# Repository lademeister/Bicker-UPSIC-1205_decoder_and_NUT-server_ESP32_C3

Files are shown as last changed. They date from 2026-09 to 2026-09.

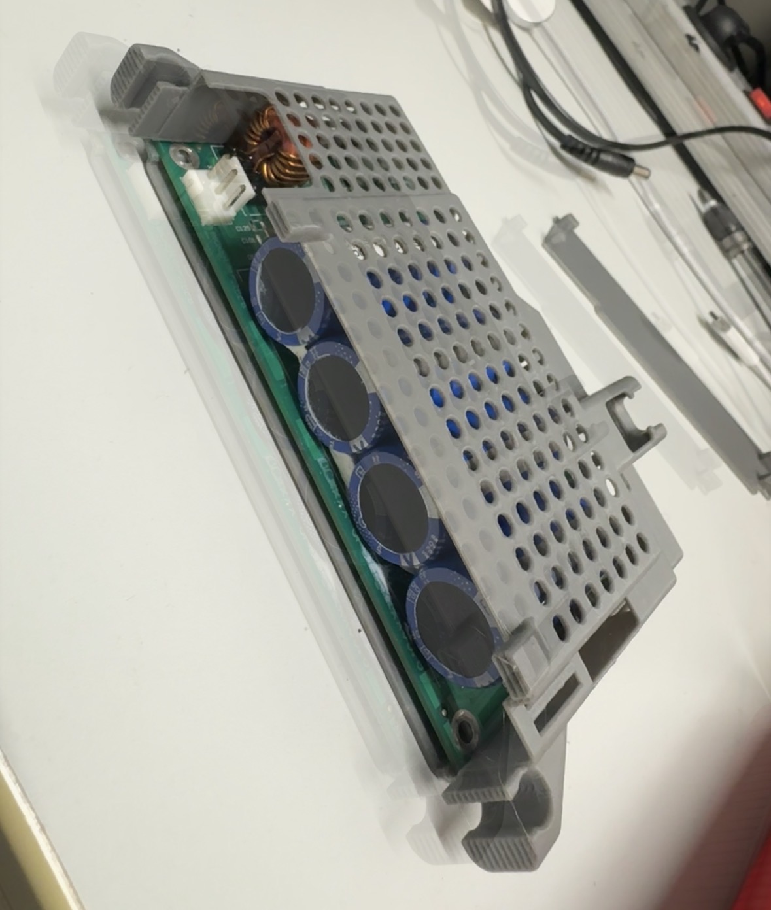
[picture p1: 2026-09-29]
Images Bicker UPSIC-1205 usage/3D printed case2.jpg

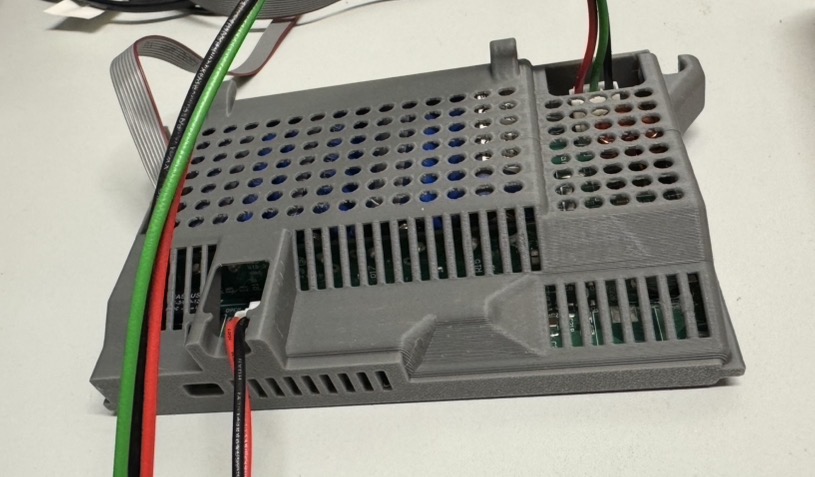
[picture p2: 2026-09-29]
Images Bicker UPSIC-1205 usage/3D printed case4.jpg

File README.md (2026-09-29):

# Bicker-UPSIC-1205 Decoder and NUT Server for ESP32-C3

This code does **NOT** require the optional and expensive **PSZ-1063 module**, as it reads the registers from the UPS module directly via I²C.

It provides:

- **NUT Server (Network UPS Tools) via Wi-Fi**
  - You can use the NUT data on multiple computers in the network.
  - It can be used for monitoring, server shutdown, etc.

- **MQTT publishing** of internal device data

- **Home Assistant Auto Discovery**
  - The UPS appears as an MQTT device in Home Assistant.

- **Optional 128×32 OLED display**
  - Shows the current UPS status.
  - Shows a remaining-runtime countdown while running on battery/supercapacitor power.

- **Optional programmable LED strip**
  - Can display the charge percentage like a bar graph.
  - Green when full.
  - Fewer LEDs as the charge level decreases.
  - Red when almost empty.
  - Flashing red shortly before power-off.
  - The behavior can be customized.

---

## Example MQTT Data

Typical data while running from mains power may look like this:

```text
UPS Charge  100 %
UPS Current 28 mA
UPS Power   0 W
UPS Runtime 0.00 s
UPS Voltage 12 V
```

The `runtime` value is used to **live-calculate the estimated remaining runtime** when running from the supercapacitors, for example after a power loss.

For this, a live calculation is performed based on the output power consumption.

The calculation uses the internal voltage and current draw, measured before the voltage converter that generates the stable 12 V output.

From this, we derive the actual wattage of the output load and calculate it back against the available energy stored in the supercapacitors.

From that, we can estimate the remaining runtime in seconds.

---

## Current Reading

The `Current` value is the actual charge/discharge current of the supercapacitors.

It will therefore be negative during a power loss and typically around approximately ±30 mA when normally powered.

Note that this is the actual current on the supercapacitor side.

As the supercapacitor voltage drops, the current must increase in order to maintain constant power at the regulated 12 V UPS output.

Therefore, you may easily see currents of around 6 A or more while your connected 12 V device only draws around 1.5 A.

This is because:

```text
P = U × I
```

Power = Voltage × Current

Therefore:

```text
P(supercapacitors) ≈ P(output)
```

The lower the supercapacitor voltage becomes, the higher the current must be to maintain approximately the same output power after boosting the voltage to 12 V.

---

## Reverse Engineering

I did the reverse engineering using a trial-and-error approach, without any knowledge of the internal register layout.

Therefore, some of my assumptions may be wrong.

However, the data derived from the module using this code appears to be quite plausible and consistent.

We decode internal register data and status information such as:

- Charge percentage
- Current
- Voltage
- Runtime
- Power status
- Other UPS status information

This code is written for the **ESP32-C3** and does **NOT** require the optional PSZ-1063 add-on module.

No serial converter or level converter is needed for the connection described here.

The ESP32 communicates directly with the small 14-pin header on the side of the UPSIC-1205.

---

## I²C Connection

For I²C communication, we only need:

```text
Pin 11  GND
Pin 12  SDA
Pin 14  SCL
```

Be very sure to count the pins correctly.

**Pin 13 is directly next to the communication pins and carries 12 V.**

Connecting Pin 13 accidentally to an ESP32 GPIO would most likely damage the ESP32.

Pin 13 could theoretically be used as a power source for the ESP32, but its maximum current of approximately 300 mA is somewhat low considering possible current spikes during Wi-Fi transmission.

You may therefore want to add a sufficiently large capacitor or simply power the ESP32 separately.

Make sure to also connect **GND between the ESP32 and the Bicker UPSIC-1205 using Pin 11**, as this provides the common voltage reference required for the I²C clock and data lines, SCL and SDA.

---

## Full Pinout

For completeness, here is the full connector pinout.

You do **NOT** need the DSUB9 connector.

You do **NOT** need the extension module.

The information normally available through those interfaces can also be accessed with this code directly from the internal registers and made available over the network via the standard NUT integration.

| Pin | Signal | DSUB9 |
|---:|---|---:|
| 01 | DCD at PC – cable connected detection | 1 |
| 02 | DSR at PC – capacitor charge-state detection | 6 |
| 03 | TXD – connected to RX at PC | 2 |
| 04 | RTS at PC – supply voltage | 7 |
| 05 | RXD – connected to TX at PC | 3 |
| 06 | CTS at PC – power-fail detection | 8 |
| 07 | N/A | |
| 08 | N/A | 9 |
| 09 | GND | 5 |
| 10 | SMBAlert | |
| **11** | **🟢 GND** | |
| **12** | **🟢 xSDA / I²C** | |
| 13 | Vout 12 V, max. 300 mA | |
| **14** | **🟢 xSCL / I²C** | |

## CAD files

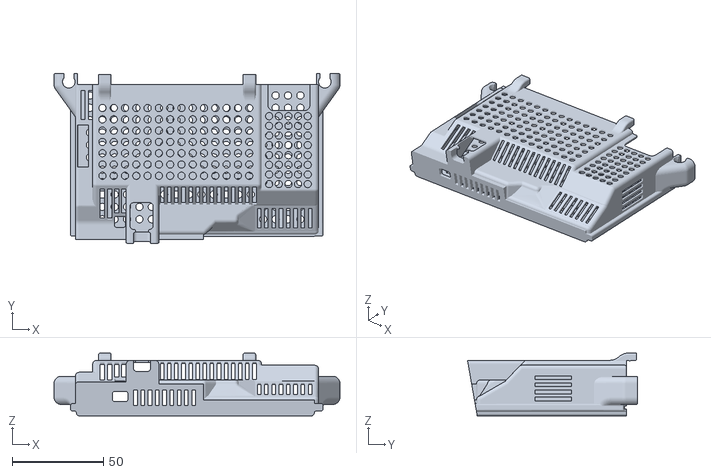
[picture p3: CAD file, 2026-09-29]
Bicker UPSIC-1205 Case 3D Print/BICKER UPSIC-1205_GEHAEUSE.stl
157.1 x 93.4 x 34.6

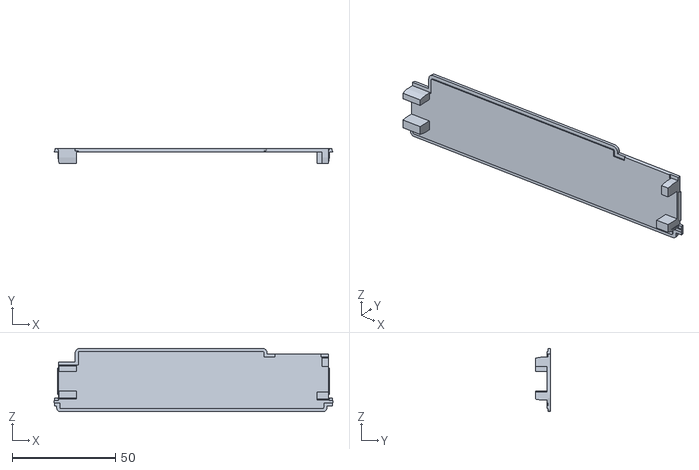
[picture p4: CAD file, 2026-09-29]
Bicker UPSIC-1205 Case 3D Print/BICKER UPSIC-1205_Gehaeusedeckel.stl
135.0 x 7.40 x 30.6

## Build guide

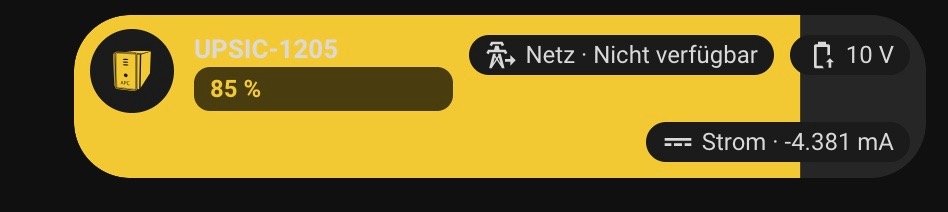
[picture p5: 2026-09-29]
Images Bicker UPSIC-1205 usage/Home Assitant Integration3.jpeg

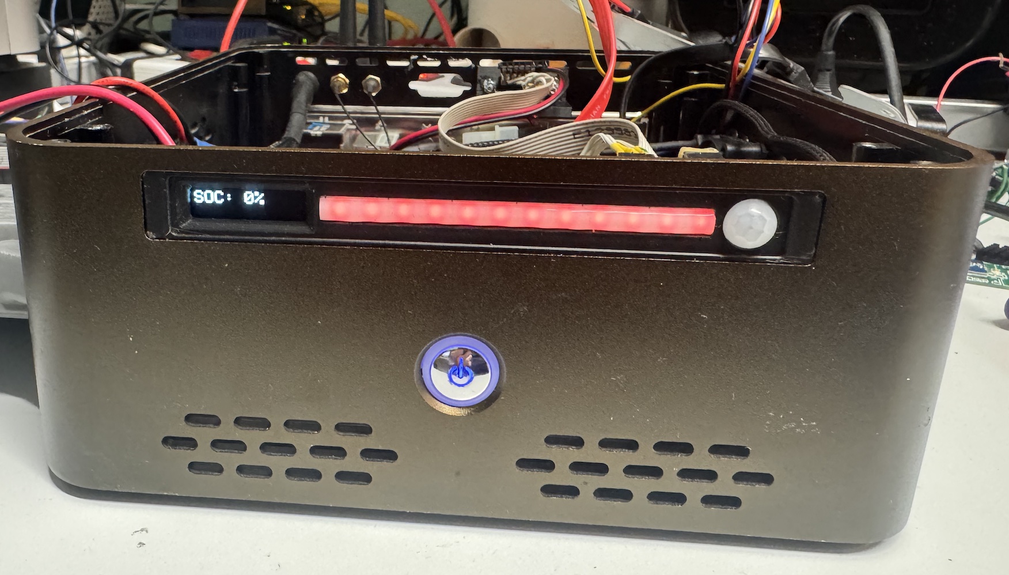
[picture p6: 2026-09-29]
Images Bicker UPSIC-1205 usage/OLED_and_LED_Bargraph_SOC0.jpg

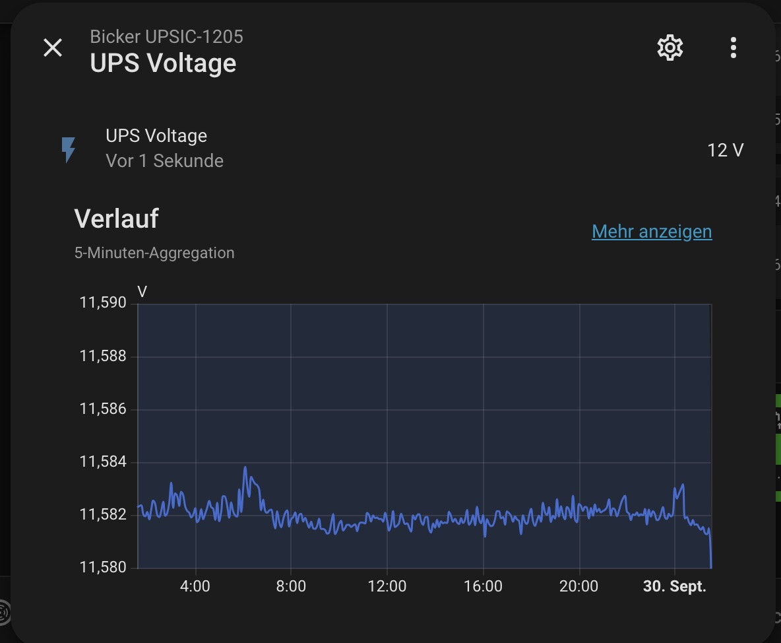
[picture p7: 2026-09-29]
Images Bicker UPSIC-1205 usage/Home Assitant Integration2.jpg

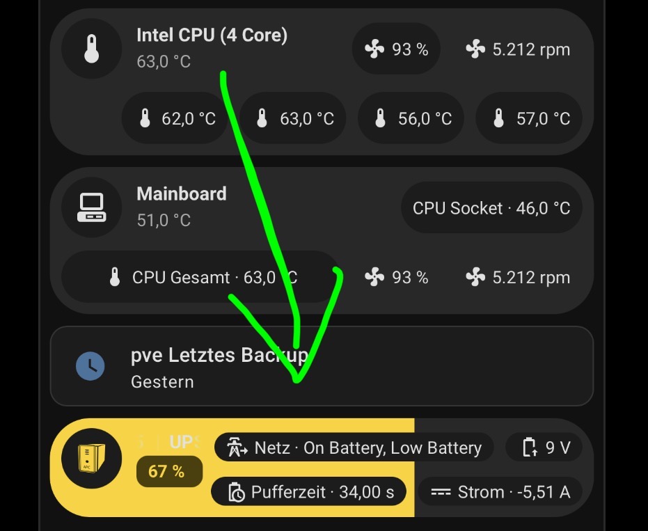
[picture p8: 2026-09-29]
Images Bicker UPSIC-1205 usage/Home Assitant Integration4.jpg

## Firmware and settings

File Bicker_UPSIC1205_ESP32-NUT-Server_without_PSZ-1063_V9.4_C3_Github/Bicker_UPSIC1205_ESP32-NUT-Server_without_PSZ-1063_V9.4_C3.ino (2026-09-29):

#include <Arduino.h>

#include "config.h"
#include "powercap.h"
#include "nutserver.h"
#include "runtime.h"
#include "ota.h"
#include "wifi_setup.h"
#include "ha_discovery.h"
#include <Wire.h>
//#include "SSD1306Ascii.h"
//#include "SSD1306AsciiWire.h"
#include <Adafruit_NeoPixel.h>
#include <Adafruit_GFX.h>
#include <Adafruit_SSD1306.h>
#include <PubSubClient.h>


HADiscovery haDiscovery;

WiFiClient mqttWiFiClient;
PubSubClient mqttClient(mqttWiFiClient);
unsigned long lastMQTTReconnect = 0;


uint8_t ledBrightness = 25;
Adafruit_NeoPixel ledstrip(NUM_LEDS, LED_PIN, NEO_GRB + NEO_KHZ800);
Adafruit_NeoPixel RGB_LED_onboard(1, 8, NEO_GRB + NEO_KHZ800);

//SSD1306AsciiWire oled;


static bool lastOnBattery = false;
static bool powerLossFlash = false;
static uint8_t flashCount = 0;
static bool flashState = false;
static unsigned long lastFlash = 0;


PowerCap powercap;

NUTServer nut;

RuntimeEstimator runtime;

OTAUpdater ota;

WiFiManagerESP wifi;

unsigned long lastPowerUpdate = 0;
unsigned long lastOLEDUpdate = 0;
unsigned long lastLEDUpdate = 0;
uint32_t lastMotionTime = 0;
bool oledOn = false;

PowerCapData displayData;

Adafruit_SSD1306 display(
  SCREEN_WIDTH,
  SCREEN_HEIGHT,
  &Wire,
  OLED_RESET
);

#include <Fonts/FreeSans9pt7b.h>
/*
FreeSans9pt7b
FreeSans12pt7b
FreeSansBold12pt7b
FreeMono9pt7b
FreeMonoBold12pt7b
 */


unsigned long lastUpdate = 0;

//void init_oled(){
//  //Wire.begin();         
//  oled.begin(&Adafruit128x32, I2C_ADDRESS_OLED);
//  oled.set400kHz();  
//  oled.setFont(Adafruit5x7); 
//  oled.set2X(); 
//
//  uint32_t m = micros();
//  oled.clear();  
//  oled.println("Bicker");
//  oled.println("UPSIC-1205");
//  delay(1000);
//  oled.clear();  
//}


void init_oled(){
  if(!display.begin(SSD1306_SWITCHCAPVCC,I2C_ADDRESS_OLED))
  {
    Serial.println("##### OLED failed #####");
    //while(true);
  }
  else{
    display.ssd1306_command(SSD1306_SEGREMAP | 0x0);
    display.ssd1306_command(SSD1306_COMSCANINC);


    display.clearDisplay();
    display.display();
    display.setTextSize(2);
    display.setTextColor(SSD1306_WHITE);
    display.setCursor(0,0);
    display.println("Bicker");
    display.println("UPSIC-1205");
    display.display();
    delay(2500);
    display.clearDisplay();
    display.display();
  }
}

void init_neopixel(){
  ledstrip.begin();
  RGB_LED_onboard.begin();
  ledstrip.setBrightness(LEDstrip_global_brightness_setting);
  RGB_LED_onboard.setBrightness(50);
//  RGB_LED_onboard.setPixelColor(0, 0, 0, 255);
//  delay(100);
//  RGB_LED_onboard.setPixelColor(0, 0, 255, 0);
//  delay(100);
  RGB_LED_onboard.setPixelColor(0, 0, 0, 0);
  //for (int i = 0; i < NUM_LEDS; i++) ledstrip.setPixelColor(i, rot, gruen, blau);
  for (int i = 0; i < NUM_LEDS; i++) ledstrip.setPixelColor(i, 0, 25, 0);
  delay(100);
  ledstrip.show();
  for (int i = 0; i < NUM_LEDS; i++) ledstrip.setPixelColor(i, 0, 0, 0);
  //ledstrip.setPixelColor(2, 5, 0, 0);
  ledstrip.show();
}

uint32_t fadeColor(
  uint32_t oldColor,
  uint32_t newColor,
  float amount
)
{

  uint8_t r1 =
    (oldColor >> 16) & 0xFF;

  uint8_t g1 =
    (oldColor >> 8) & 0xFF;

  uint8_t b1 =
    oldColor & 0xFF;


  uint8_t r2 =
    (newColor >> 16) & 0xFF;

  uint8_t g2 =
    (newColor >> 8) & 0xFF;

  uint8_t b2 =
    newColor & 0xFF;



  uint8_t r =
    r1 + (r2-r1)*amount;

  uint8_t g =
    g1 + (g2-g1)*amount;

  uint8_t b =
    b1 + (b2-b1)*amount;


  return ledstrip.Color(r,g,b);

}

//void updateLEDs()
//{
//
//  static uint32_t currentColors[NUM_LEDS];
//
//  static bool blinkState = false;
//
//  static unsigned long lastBlink = 0;
//
//
//  if(
//    millis()-lastBlink > 500
//  )
//  {
//
//    lastBlink = millis();
//
//    blinkState = !blinkState;
//
//  }
//
//
//
//  float soc =
//    constrain(
//      displayData.soc,
//      0,
//      100
//    );
//
//
//  uint8_t activeLEDs =
//    map(
//      soc,
//      0,
//      100,
//      0,
//      NUM_LEDS
//    );
//
//
//
//  bool critical =
//    (
//      displayData.onBattery &&
//      soc < 90
//    );
//
//
//
//  bool charging =
//    displayData.charging;
//
//
//
//  for(
//    int i=0;
//    i<NUM_LEDS;
//    i++
//  )
//  {
//    int pixel = NUM_LEDS - 1 - i;
//
//    uint32_t target;
//
//
//
//    // -------------------------
//    // Charging animation
//    // -------------------------
//
//    if(charging)
//    {
//
//      uint8_t wave =
//        //(millis()/50+i*20)%255;
//        (millis()/50+(NUM_LEDS-1-i)*20)%255; //inverted direction
//
//
//      target =
//        ledstrip.Color(
//          wave,
//          0,
//          80
//        );
//
//    }
//
//
//
//
//
//
//
//    // -------------------------
//    // SOC bargraph
//    // -------------------------
//
//    else if(i < activeLEDs)
//    {
//
//      if(soc > 60)
//      {
//
//        target =
//          ledstrip.Color(
//            0,
//            ledBrightness,
//            0
//          );
//
//      }
//
//      else if(soc > 30)
//      {
//
//        target =
//          ledstrip.Color(
//            ledBrightness,
//            ledBrightness,
//            0
//          );
//
//      }
//
//      else
//      {
//
//        target =
//          ledstrip.Color(
//            ledBrightness,
//            0,
//            0
//          );
//
//      }
//
//    }
//
//
//    // -------------------------
//    // empty LEDs
//    // -------------------------
//
//    else
//    {
//
//      target =
//        ledstrip.Color(8,0,0);
//    }
//
//
//
//    // -------------------------
//    // first LED warning blink
//    // -------------------------
//
//    if(
//      critical &&
//      i==0
//    )
//    {
//
//      if(blinkState)
//      {
//        target =
//          ledstrip.Color(
//            0,
//            ledBrightness,
//            0
//          );
//      }
//      else
//      {
//        target =
//          ledstrip.Color(
//            ledBrightness,
//            0,
//            0
//          );
//      }
//
//    }
//
//
//
//    uint32_t old =
//      currentColors[i];
//
//
//    currentColors[i] =
//      fadeColor(
//        old,
//        target,
//        0.15
//      );
//
//
//    //ledstrip.setPixelColor(i,currentColors[i]);
//    ledstrip.setPixelColor(pixel,currentColors[i]);
//
//
//  }
//
//
//  ledstrip.show();
//
//}


//void updateLEDs()
//{
//  static uint32_t currentColors[NUM_LEDS];
//  static bool blinkState = false;
//  static bool fastBlinkState = false;
//  static unsigned long lastBlink = 0;
//  static unsigned long lastFastBlink = 0;
//
//  if(millis()-lastBlink > 500)
//  {
//    lastBlink = millis();
//    blinkState = !blinkState;
//  }
//
//  if(millis()-lastFastBlink > 150)
//  {
//    lastFastBlink = millis();
//    fastBlinkState = !fastBlinkState;
//  }
//
//
//  float soc = constrain(displayData.soc,0,100);
//
//  uint8_t activeLEDs = map(soc,0,100,0,NUM_LEDS);
//
//  bool critical = displayData.onBattery && soc < 90;
//  bool veryLow = displayData.onBattery && soc < 30;
//  bool charging = displayData.charging;
//
//
//  uint32_t barColor;
//
//  if(soc > 60)
//    barColor = ledstrip.Color(0,ledBrightness,0);
//  else if(soc > 30)
//    barColor = ledstrip.Color(ledBrightness,ledBrightness,0);
//  else
//    barColor = ledstrip.Color(ledBrightness,0,0);
//
//
//
//  for(int i=0;i<NUM_LEDS;i++)
//  {
//    int pixel = NUM_LEDS-1-i;
//
//    uint32_t target;
//
//
//    // SOC bargraph
//    if(i < activeLEDs)
//    {
//      target = barColor;
//    }
//
//    // inactive LEDs
//    else
//    {
//      if(charging)
//        target = ledstrip.Color(8,0,8);   // dark purple
//      else
//        target = ledstrip.Color(8,0,0);   // dark red
//    }
//
//
//
//    // low battery warning
//    if(critical && i==0)
//    {
//
//      if(veryLow)
//      {
//        // fast red flash below 30%
//        if(fastBlinkState)
//          target = ledstrip.Color(ledBrightness,0,0);
//        else
//          target = ledstrip.Color(0,0,0);
//      }
//      else
//      {
//        // normal warning blink
//        if(blinkState)
//          target = barColor;
//        else
//          target = ledstrip.Color(ledBrightness,0,0);
//      }
//
//    }
//
//
//
//    currentColors[i] =
//      fadeColor(
//        currentColors[i],
//        target,
//        0.15
//      );
//
//
//    ledstrip.setPixelColor(
//      pixel,
//      currentColors[i]
//    );
//
//  }
//
//
//  ledstrip.show();
//}



void updateLEDs()
{
//  static uint32_t currentColors[NUM_LEDS];
//  static bool blinkState = false;
//  static bool fastBlinkState = false;
//  static unsigned long lastBlink = 0;
//  static unsigned long lastFastBlink = 0;

  static uint32_t currentColors[NUM_LEDS];
  static bool blinkState = false;
  static bool fastBlinkState = false;
  static unsigned long lastBlink = 0;
  static unsigned long lastFastBlink = 0;

  static bool lastOnBattery = false;
  static bool powerLossFlash = false;
  static uint8_t flashCount = 0;
  static bool flashState = false;
  static unsigned long lastFlash = 0;

  uint32_t now = millis();
  // detect transition from grid power to battery
if(displayData.onBattery && !lastOnBattery)
{
  powerLossFlash = true;
  flashCount = 0;
  flashState = true;
  lastFlash = now;
}

lastOnBattery = displayData.onBattery;


// 4x full red flash on power loss
  if(powerLossFlash)
  {
    if(now - lastFlash > 200)
    {
      lastFlash = now;
      flashState = !flashState;
  
      if(!flashState)
      {
        flashCount++;
  
        if(flashCount >= 4)
          powerLossFlash = false;
      }
    }
  
  
    uint32_t flashColor;
  
    if(flashState){
      //flashColor = ledstrip.Color(ledBrightness,0,0);
      ledstrip.setBrightness(flashBrightness);
      flashColor = ledstrip.Color(flashBrightness,0,0);
    }
    else{
      flashColor = ledstrip.Color(0,0,0);
    }
  
    for(int i=0;i<NUM_LEDS;i++)
    {
      ledstrip.setPixelColor(i, flashColor);
    }
  
    ledstrip.show();
    return;
  }

  else{
    ledstrip.setBrightness(LEDstrip_global_brightness_setting);
  }

  
  if(millis()-lastBlink > 500)
  {
    lastBlink = millis();
    blinkState = !blinkState;
  }

  if(millis()-lastFastBlink > 150)
  {
    lastFastBlink = millis();
    fastBlinkState = !fastBlinkState;
  }


  float soc = constrain(displayData.soc,0,100);

  uint8_t activeLEDs = map(soc,0,100,0,NUM_LEDS);

  bool critical = displayData.onBattery && soc < 90;
  bool veryLow = displayData.onBattery && soc < 30;
  bool charging = displayData.charging;


  uint32_t barColor;

//  if(soc > 60)
//    barColor = ledstrip.Color(0,ledBrightness,0);
//  else if(soc > 30)
//    barColor = ledstrip.Color(ledBrightness,ledBrightness,0);
//  else
//    barColor = ledstrip.Color(ledBrightness,0,0);


    if(displayData.onBattery && soc < 30)
    {
      // critical battery
      barColor = ledstrip.Color(ledBrightness,0,0);
    }
    else if(displayData.onBattery && soc < 95)
    {
      // battery discharge warning (orange/red)
      barColor = ledstrip.Color(ledBrightness,60,0);
    }
    else
    {
      if(soc > 60)
        barColor = ledstrip.Color(0,ledBrightness,0);
      else if(soc > 30)
        barColor = ledstrip.Color(ledBrightness,ledBrightness,0);
      else
        barColor = ledstrip.Color(ledBrightness,0,0);
    }

  for(int i=0;i<NUM_LEDS;i++)
  {
    int pixel = NUM_LEDS-1-i;

    uint32_t target;


    // SOC bargraph
    if(i < activeLEDs)
    {
      target = barColor;
    }

    // inactive LEDs
    else
    {
      if(charging)
        target = ledstrip.Color(8,0,8);   // dark purple
      else
        target = ledstrip.Color(8,0,0);   // dark red
    }



//    // low battery warning
//    if(critical && i==0)
//    {
//
//      if(veryLow)
//      {
//        // fast red flash below 30%
//        if(fastBlinkState)
//          target = ledstrip.Color(ledBrightness,0,0);
//        else
//          target = ledstrip.Color(0,0,0);
//      }
//      else
//      {
//        // normal warning blink
//        if(blinkState)
//          target = barColor;
//        else
//          target = ledstrip.Color(ledBrightness,0,0);
//      }
//
//    }



    currentColors[i] =
      fadeColor(
        currentColors[i],
        target,
        0.15
      );


    ledstrip.setPixelColor(
      pixel,
      currentColors[i]
    );

  }


  ledstrip.show();
}

void setup()
{

  Serial.begin(115200);

  delay(500);



  Serial.println();
  Serial.println("===============================");
  Serial.println(" Bicker UPSIC-1205 NUT ESP32");
  Serial.println("===============================");

  pinMode(PIR_pin, INPUT_PULLDOWN);


  // -------------------------
  // I2C PowerCap
  // -------------------------

  powercap.begin(); //incl i2c init
  Serial.println("PowerCap initialized");


  init_oled();
  init_neopixel();

  runtime.begin();

  // -------------------------
  // WiFi
  // -------------------------

  wifi.begin();


  Serial.print("IP: ");
  Serial.println(
    wifi.getIP()
  );



  // -------------------------
  // OTA
  // -------------------------

  ota.begin();



  // -------------------------
  // NUT Server
  // -------------------------

  nut.begin();


  Serial.println(
    "NUT server started on port 3493"
  );

  mqttClient.setServer(
  MQTT_SERVER,
  MQTT_PORT
);
mqttClient.setBufferSize(1024);

haDiscovery.begin(mqttClient);

}


//void oled_update(){
//  oled.clear();  
//  oled.println("USV");
//  oled.print("SOC = ");
//  oled.print(data.soc,1);
//  oled.println(" %");
//}

void updateOLED()
{
//  if(displayData.soc>99){
//    display.clearDisplay();
//    display.display();
//    return;
//  }
//  static float lastVoltage = -1;
//  static float lastSOC = -1;
//  static uint8_t lastState = 255;

  static float lastVoltage = -1;
  static float lastSOC = -1;
  static uint8_t lastState = 255;
  static bool lastOnBattery = false;
  static bool powerLossFlash = false;


  if(
    displayData.soc == lastSOC &&
    displayData.soc>99
  )
  {
    return;
  }

  if(
    displayData.voltage == lastVoltage &&
    displayData.soc == lastSOC &&
    displayData.state == lastState
  )
  {
    return;
  }


  lastVoltage = displayData.voltage;
  lastSOC = displayData.soc;
  lastState = displayData.state;


  display.clearDisplay();

  display.setTextSize(1);
  display.setCursor(0,0);
//
//  display.print("UPSIC1205");
//
//
//  display.setCursor(0,12);
  display.setTextSize(2);
  //display.setFont(&FreeSans9pt7b);
  display.setCursor(0, 3);
  display.print("SOC: ");
  display.print(displayData.soc,0);
  display.println("%");

//  display.setTextSize(2);
//  display.print("V: ");
//  display.print(displayData.voltage,2);
//  display.print("V - ");


  //display.println(displayData.stateText);
  if (displayData.state == 10)
  {
      display.print("Puffer:");
      display.print(runtime.getRuntimeSeconds());
      display.println("s");
  }
  else
  {
      display.println(displayData.stateText);
  }
  
  //display.println("-test-");


  display.display();

}



void display_off(){
    
    display.clearDisplay();
    display.display();
}



void handleOLEDTimeout()
{
    static bool lastPirState = false;

    bool pirState = digitalRead(PIR_pin) == HIGH;
  
    
    
//  //debug_pir_state:
//      if (pirState!=lastPirState){
//      if (pirState){    
//        ledstrip.setPixelColor(NUM_LEDS-11, 255, 0, 0);
//        ledstrip.show();
//      }
//      else{
//        ledstrip.setPixelColor(NUM_LEDS-11, 0, 0, 255);
//        ledstrip.show();
//      }
//    }
//
//  //END of debug pir state  


    
    // Motion detected
    if (pirState)
    {
        lastMotionTime = millis();

        if (!oledOn)
        {
            oledOn = true;
//            display_on();aaaa
        }
    }

    // OLED timeout
    if (oledOn && (millis() - lastMotionTime >= 1000UL)) // 10s test
    //if (oledOn && (millis() - lastMotionTime >= 20UL * 60UL * 1000UL)) //20 min
    {
        oledOn = false;
        display_off();
    }

    // Update display continuously while OLED is on
    if (oledOn)
    {
        updateOLED();
    }
}


//void //publishDebugTiming(const char* functionName, uint32_t duration)
//{
//  char msg[64];
//
//  snprintf(
//    msg,
//    sizeof(msg),
//    "%s:%lums",
//    functionName,
//    duration
//  );
//
//  mqttClient.publish(
//    "server/bicker_ups/debug",
//    msg
//  );
//}

//void //publishDebugTiming(const char* functionName,uint32_t duration)
//{
//  if(duration < 50)
//    return;
//
//  char msg[64];
//
//  snprintf(
//    msg,
//    sizeof(msg),
//    "%s:%lums",
//    functionName,
//    duration
//  );
//
//  mqttClient.publish(MQTT_TOPIC_DEBUG,msg);
//}


//void //publishDebugTiming(const char* functionName,uint32_t duration)
//{
//  if(!mqttClient.connected())
//    return;
//
//  if(duration < 50)
//    return;
//
//  char msg[64];
//
//  snprintf(
//    msg,
//    sizeof(msg),
//    "%s:%lums",
//    functionName,
//    duration
//  );
//
//  mqttClient.publish(
//    MQTT_TOPIC_DEBUG,
//    msg
//  );
//}

//void //publishDebugTiming(const char* functionName,uint32_t duration)
//{
//  char msg[64];
//
//  snprintf(
//    msg,
//    sizeof(msg),
//    "%s:%lums",
//    functionName,
//    duration
//  );
//
//  mqttClient.publish(
//    MQTT_TOPIC_DEBUG,
//    msg
//  );
//}

void publishDebugTiming(const char* functionName,uint32_t duration)
{
  char topic[96];
  char msg[32];


  snprintf(
    topic,
    sizeof(topic),
    "%s/%s",
    MQTT_TOPIC_DEBUG,
    functionName
  );


  snprintf(
    msg,
    sizeof(msg),
    "%lums",
    duration
  );


  mqttClient.publish(
    topic,
    msg
  );
}
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
void loop()
{

  uint32_t start;


  start = millis();
  handleOLEDTimeout();
  //publishDebugTiming("handleOLEDTimeout",millis() - start);



  if (millis() - lastLEDUpdate > 20)
  {
    lastLEDUpdate = millis();

    start = millis();
    updateLEDs();
    //publishDebugTiming("updateLEDs",millis() - start);
  }



  if (oledOn && millis() - lastOLEDUpdate >= 100)
  {
    lastOLEDUpdate = millis();

    start = millis();
    updateOLED();
    //publishDebugTiming("updateOLED",millis() - start);
  }



  start = millis();
  wifi.loop();
  //publishDebugTiming("wifi.loop",millis() - start);



  start = millis();
  nut.handle();
  //publishDebugTiming("nut.handle",millis() - start);



  start = millis();
  ota.loop();
  //publishDebugTiming("ota.loop",millis() - start);



  start = millis();

//  if(!mqttClient.connected())
//  {
////    mqttClient.connect("Bicker_UPSIC-1205-ESP32");
//    mqttClient.connect(
//      "Bicker_UPSIC-1205-ESP32",
//      MQTT_USER,
//      MQTT_PASSWORD
//    );
//  }
//
//  //publishDebugTiming("mqtt.connect",millis() - start);
//
//
//
//  start = millis();
//
//  mqttClient.loop();
//
//  //publishDebugTiming("mqtt.loop",millis() - start);

//if(!mqttClient.connected())
//{
//  if(millis() - lastMQTTReconnect > 10000)
//  {
//    lastMQTTReconnect = millis();
//
//    start = millis();
//
//    mqttClient.connect(
//      "Bicker_UPSIC-1205-ESP32",
//      MQTT_USER,
//      MQTT_PASSWORD
//    );
//
//    //publishDebugTiming("mqtt.connect",millis() - start);
//  }
//}
start = millis();

mqttReconnect();

//publishDebugTiming("mqtt.connect",millis() - start);


start = millis();

mqttClient.loop();

//publishDebugTiming("mqtt.loop",millis() - start);

  uint32_t interval = displayData.onBattery ? 300 : 500;


  if(millis() - lastUpdate >= interval)
  {

    lastUpdate = millis();


    start = millis();

    bool updated = powercap.update();

    //publishDebugTiming("powercap.update",millis() - start);



    if(updated)
    {

      start = millis();

      PowerCapData data = powercap.getData();
      displayData = data;

      char buffer[32];

      snprintf(buffer,sizeof(buffer),"%.0f",data.soc);
      mqttClient.publish("server/bicker_ups/soc",buffer,true);
      
      snprintf(buffer,sizeof(buffer),"%.2f",data.voltage);
      mqttClient.publish("server/bicker_ups/voltage",buffer,true);
      
      snprintf(buffer,sizeof(buffer),"%.0f",data.current);
      mqttClient.publish("server/bicker_ups/current",buffer,true);
      
      snprintf(buffer,sizeof(buffer),"%.2f",data.power);
      mqttClient.publish("server/bicker_ups/power",buffer,true);
      
      snprintf(buffer,sizeof(buffer),"%lu",(unsigned long)runtime.getRuntimeSeconds());
      mqttClient.publish("server/bicker_ups/runtime",buffer,true);
      
      mqttClient.publish("server/bicker_ups/status",nut.getStatus().c_str(),true);

      runtime.update(
        data.soc,
        data.current,
        data.onBattery,
        data.state,
        data.voltage
      );

      //publishDebugTiming("runtime.update",millis() - start);



      start = millis();

      nut.update(data,runtime);

      //publishDebugTiming("nut.update",millis() - start);

    }

  }


}

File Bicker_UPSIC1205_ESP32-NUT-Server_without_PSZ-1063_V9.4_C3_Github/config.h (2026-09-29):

#ifndef CONFIG_H
#define CONFIG_H


// ===============================
// WiFi
// ===============================

#define WIFI_SSID       "YOUR-WIFI-SSID"
#define WIFI_PASSWORD   "YOUR-WIFI-PASSWORD"

#define MQTT_SERVER "192.168.178.2"
#define MQTT_PORT   1883
#define MQTT_TOPIC_DEBUG "server/bicker_ups/debug"
#define MQTT_USER     "bicker"
#define MQTT_PASSWORD "YOURpassword"


#define WIFI_HOSTNAME   "Bicker_UPSIC-1205-esp32"
#define OTA_HOSTNAME    "Bicker_UPSIC-1205-esp32"


// ===============================
// UPS Identification
// ===============================

#define UPS_NAME        "UPSIC1205"
#define UPS_VENDOR      "BICKER"
#define UPS_MODEL       "UPSIC-1205"

// ===============================
// I2C OLED
// ===============================
// 0X3C+SA0 - 0x3C or 0x3D
#define I2C_ADDRESS_OLED 0x3C
#define SCREEN_WIDTH 128
#define SCREEN_HEIGHT 32
#define OLED_RESET -1



#define PIR_pin 2
// ===============================
// Neopixel
// ===============================
#define LED_PIN      1
#define NUM_LEDS     12
#define LEDstrip_global_brightness_setting 50 //range: 0-255
#define flashBrightness 255

extern uint8_t ledBrightness;

// ===============================
// I2C PowerCap
// ===============================

#define I2C_ADDRESS     0x09


// ESP32 I2C Pins
#define I2C_SDA         4
#define I2C_SCL         3



// ===============================
// PowerCap Registers
// ===============================

#define REG_STATE       0x1B

#define REG_SOC_RAW     0x25

#define REG_CAP_RAW     0x26

#define REG_ESR1        0x27
#define REG_ESR2        0x28

#define REG_CURRENT     0x29

#define REG_MISC        0x2A



// ===============================
// Voltage conversion
//
// Determined from measurements:
//
// RAW 3487 = 5.719V
// RAW 4960 = 8.134V
//
// factor ≈ 0.00164 V/count
//
// ===============================

#define CAP_VOLT_FACTOR 0.00164f



// ===============================
// Current conversion
//
// Raw signed values:
// -4053 -> discharge
// +16294 -> charge
//
// scale to mA
// ===============================

#define CURRENT_FACTOR  1.0f



// ===============================
// SOC mapping
//
// Based on measured discharge curve
//
// 8.57V  = 90%
// 8.13V  = charging region
// 5.72V  = lower battery
// 1.63V  = shutdown
//
// ===============================

#define SOC_FULL_VOLTAGE       8.57f
#define SOC_EMPTY_VOLTAGE      1.63f



// Shutdown threshold
// Hardware shutdown happened at:
// approx 1.6V

#define SOC_SHUTDOWN_PERCENT   0.0f



// ===============================
// NUT Server
// ===============================

#define NUT_PORT 3493


#endif

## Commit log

2026-09-29 upload first public version
    this is a reverse engineering of the internal data structure of Bicker UPSIC-1205 supercap USV (12V DC), without guarantee to be correct with my guessings.
    [Bicker_UPSIC1205_ESP32-NUT-Server_without_PSZ-1063_V9.4_C3.ino, config.h, nutserver.cpp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]
2026-09-29 Enhance README with detailed project description
    Expanded README with detailed functionality and setup instructions for the Bicker UPSIC-1205 decoder and NUT server on ESP32-C3. Included information on I2C communication, pinout, and device capabili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
2026-09-29 first upload
    [BICKER UPSIC-1205_GEHAEUSE.stl, BICKER UPSIC-1205_Gehaeusedeckel.stl]
